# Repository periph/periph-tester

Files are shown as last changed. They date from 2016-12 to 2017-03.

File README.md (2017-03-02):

Periph-Tester Board
===================

The periph-tester board is a small PCB used to test the https://periph.io/x/periph
hardware device interface library.

pcb

The board allows simple testing of i2c, spi, 1-wire, pwm, and analog.
- Gpio can be tested by connecting two pins (preferably interrupt-capable) outside the board.
- I2C can be tested by exercising an i2c eeprom and the i2c to 1-wire interface chip.
- SPI can be tested by exercising an spi eeprom.
- 1-wire can be tested be exercising a 1-wire eeprom and a 1-wire temperature sensor.
- PWM and ADC can be tested by outputting waveforms with varying duty cycles and reading the level of a low-pass filter.
- A gpio pin is connected to the write-enable of the I2C and SPI eeproms and can be used to
  simulate certain errors by write-protecting the eeproms. (In hindsight this creates more pain
  in ensuring the pin is set correctly than it has true value...)

Standard pin-outs
-----------------
The recommended pin-outs for various platforms are as follows.

| Function | Raspberry Pi | C.H.I.P. | ODROID-C1 |
| --- | --- | --- | --- |
| i2c bus  | pins 3&5 | TWI1 (bus 1)<br>pins U13 9&11 | i2ca (bus 1)<br>pins 3&5  |
| spi bus  | pins 19,21,23,24 | bus 32766<br>pins U14 27-30 | bus 0<br>pins 19,21,23,24 |
| wr-en | pin 7 | csid0(132)<br>pin U14-31 | gpio83<br>pin 7 |
| LED | pin 31 | csid1(133)<br>pin U14-32 | gpio100<br>pin 31 |
| PWM | | pwm0(34)<br>pin U13-18 | gpio108<br>pin 33 |
| ADC | N/C | lradc<br>pin U14-11 | adc.ain1<br>pin 37 |
| GPIO | | xio-p6&p7<br>pins U14-19&20<br>ap-eint1&ap-eint3<br>pins U14-23&24 | |

Usage
-----

### CHIP
To enable SPI, see http://www.chip-community.org/index.php/Hardware_Information
- gpio-write 133 1
- periph-smoketest -v i2c-testboard -bus 1 -wc 132
- periph-smoketest -v spi-testboard -wp 132
- periph-smoketest -v onewire-testboard -i2cbus 1
- periph-smoketest -v gpio 1019 1020
- periph-smoketest -v gpio 35 193
- gpio-write 133 0

### ODROID-C1
- periph-smoketest -v i2c-testboard -bus 2 -wc 83
- periph-smoketest -v spi-testboard -wp 83
- periph-smoketest -v onewire-testboard -i2cbus 1
- periph-smoketest -v gpio 104 115

## Raspberry Pi
- periph-smoketest -v i2c-testboard -bus 1 -wc 4
- periph-smoketest -v spi-testboard -wp 4
- periph-smoketest -v onewire-testboard -i2cbus 1
- periph-smoketest -v gpio 22 23

PCB and Parts
-------------
The PCB can be [ordered from OSH park](https://oshpark.com/shared_projects/Lhlb9MeB),
3 PCBs cost $3.75 incl shipping.
Parts can be ordered from digikey:
- M24C08 (i2c eeprom): 497-15752-1-ND
- M95080 (spi eeprom): 497-8683-1-ND
- DS2483 (i2c 1-wire interface): DS2483R+TCT-ND
- DS2431 (1-wire eeprom): DS2431+-ND
- MAX31820 (1-wire temp sensor): MAX31820MCR+-ND
- TVS diode: CDSOD323-T03SCT-ND
- LED:
- 1.8v Zener: MMSZ4678-TPMSCT-ND
- 4.7uF cap:
- 100uF cap, 4.7k resistors, 2.2k resistor: all std 0603 parts

Total parts cost: ~$10.
If you are contributing to periph and would like
an assembled board, contact the author.

Author
------
Thorsten von Eicken

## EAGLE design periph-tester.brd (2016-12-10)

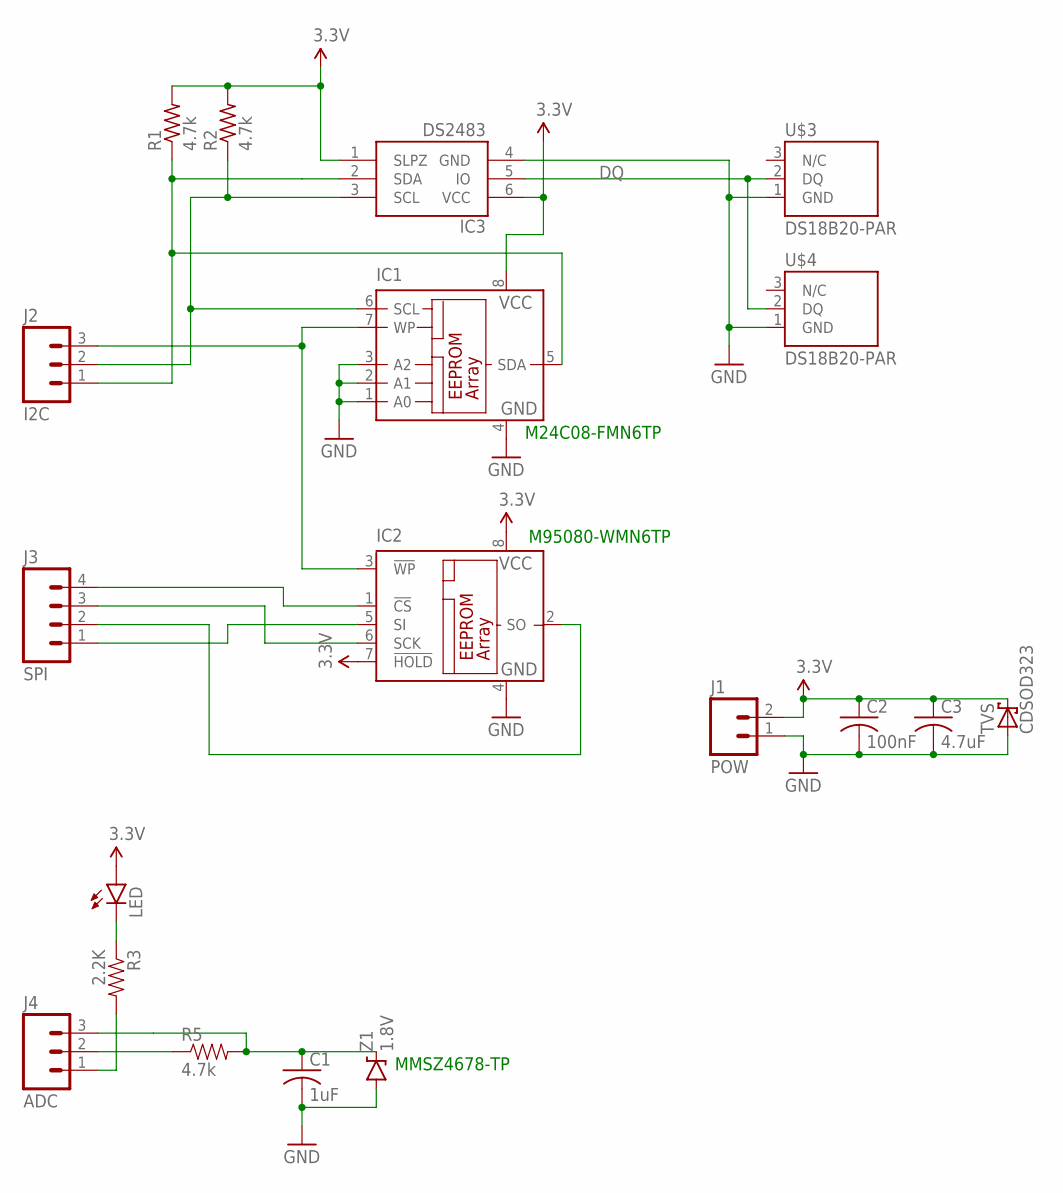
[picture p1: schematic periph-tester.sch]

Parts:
C1: 1uF; C0603K
C2: 100nF; C0603K
C3: 4.7uF; C0805K
IC1: 24C04SN; SO-08
IC2: 25C080SN; SO-08
IC3: DS2483; SOT23-6
J1: POW; 1X02
J2: I2C; 1X03
J3: SPI; 1X04
J4: ADC; 1X03
LED: LED0603; LED-0603
R1, R2: 4.7k; R0603
R3: 2.2K; 0603-RES
R5: 4.7k; 0603-RES
TVS: CDSOD323; SOD323-W
U$3, U$4: DS18B20-PAR; TO-92
Z1: 1.8V; SOD-123

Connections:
3.3V: C2.1, C3.1, IC1.8 (VCC), IC2.7 (!HOLD), IC2.8 (VCC), IC3.1 (SLPZ), IC3.6 (VCC), J1.2, LED.A, R1.2, R2.2, TVS.C
DQ: IC3.5 (IO), U$3.2 (DQ), U$4.2 (DQ)
GND: C1.2, C2.2, C3.2, IC1.1 (A0), IC1.2 (A1), IC1.3 (A2), IC1.4 (GND), IC2.4 (GND), IC3.4 (GND), J1.1, TVS.A, U$3.1 (GND), U$4.1 (GND), Z1.A
unnamed: IC1.6 (SCL), IC3.3 (SCL), J2.2, R2.1
unnamed: LED.C, R3.1
unnamed: IC1.5 (SDA), IC3.2 (SDA), J2.1, R1.1
unnamed: IC2.5 (SI), J3.1
unnamed: IC2.6 (SCK), J3.3
unnamed: IC2.2 (SO), J3.2
unnamed: IC2.1 (!CS), J3.4
unnamed: J4.1, R3.2
unnamed: IC1.7 (WP), IC2.3 (!WP), J2.3
unnamed: J4.2, R5.1
unnamed: C1.1, J4.3, R5.2, Z1.C

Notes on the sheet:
MMSZ4678-TP
M24C08-FMN6TP
M95080-WMN6TP

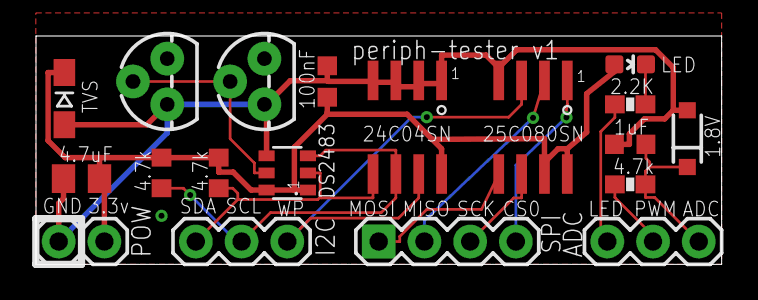
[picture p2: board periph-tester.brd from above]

Board: 2 copper layers, 38.1 x 12.7 mm, 19 parts (0 on the bottom side), 14 nets.

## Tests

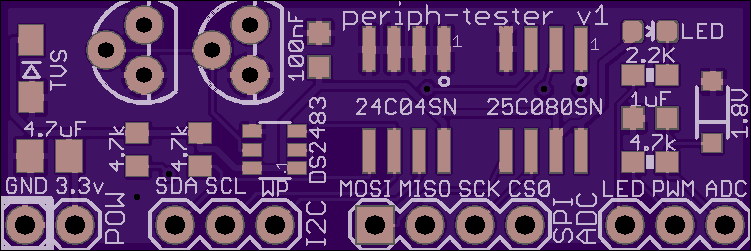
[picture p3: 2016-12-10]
tester-board.png

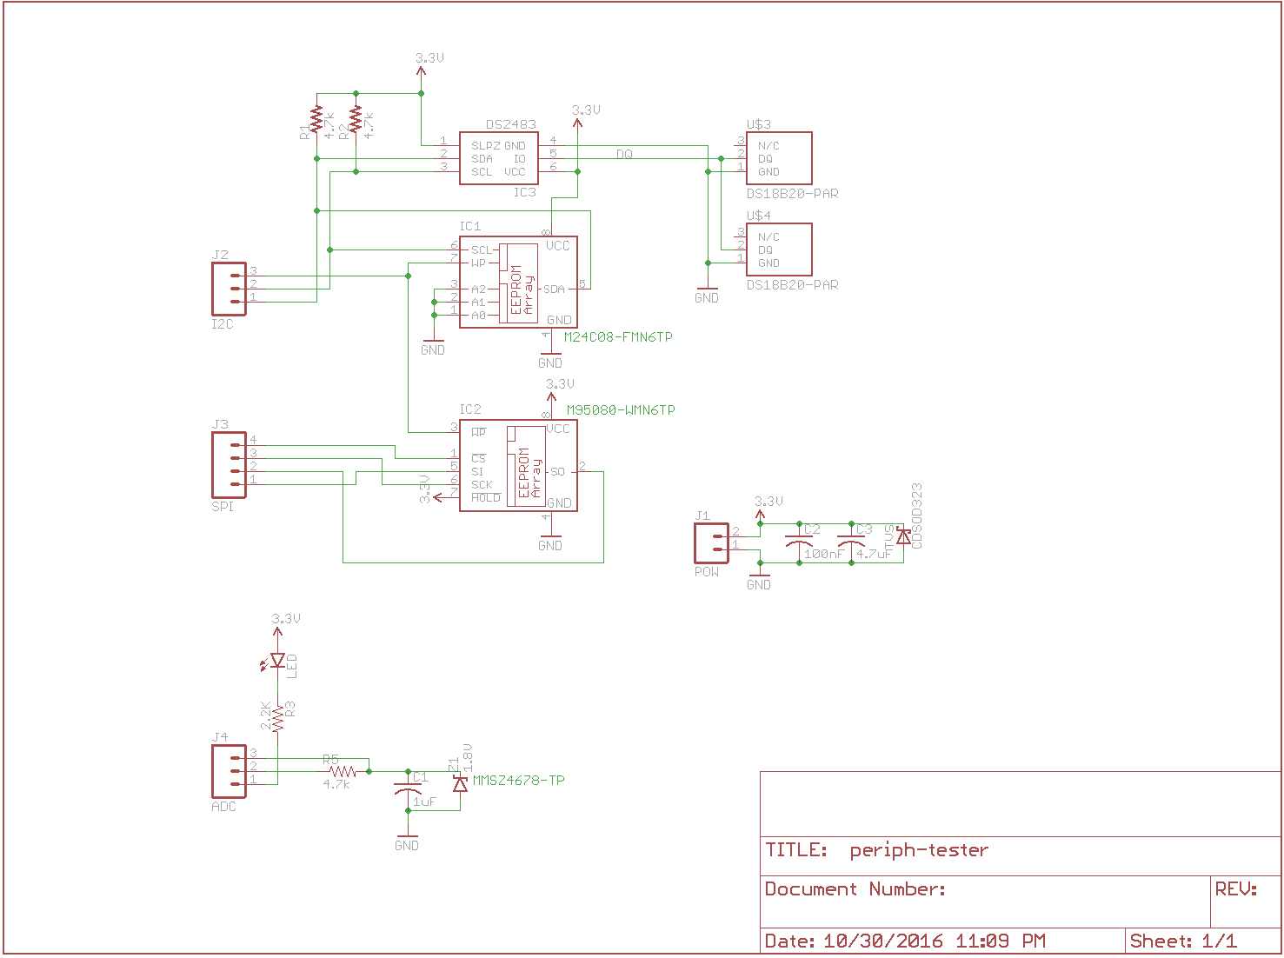
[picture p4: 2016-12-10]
tester-schem.png

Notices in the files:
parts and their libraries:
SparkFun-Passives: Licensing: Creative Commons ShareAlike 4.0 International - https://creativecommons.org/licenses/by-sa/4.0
